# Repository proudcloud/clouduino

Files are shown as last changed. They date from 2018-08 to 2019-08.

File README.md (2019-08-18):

# Clouduino

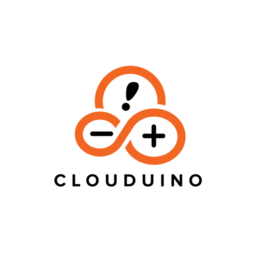
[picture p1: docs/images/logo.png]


Clouduino is a fully open-source, WiFi mesh-enabled embedded development platform.

This project is still in its infancy. At the moment, the circuit design and PCB layout for the initial prototype version is available for building the initial iteration of the board: Clouduino Stratus. We also included sample code to get you started. We will be producing limited quantities of the board soon. In the meantime, let's build our own boards, send us your feed back and help this project grow.

## Specs

- CPU: 160 MHz
- L106 32-bit RISC Tensilica Xtensa Diamond Standard 106Micro
- 3.3V supply power
- Flash Memory: 4MB
- 16 GPIO pins
- 8 analog input channels with 12-bit resolution (programmable as single-ended or pseudo-differential pairs)
- SPI
- I2C support
- 12-bit SAR ADC support
- IEEE 802.11 b/g/n WiFi (w/ WEP, WPA, WPA2)

## Getting Started
Check out our Get Started Guide [here](https://github.com/proudcloud/clouduino/tree/master/getStarted).

## Quickstart Guide

1. Download and install [Arduino IDE](https://www.arduino.cc/en/Main/Software)
2. Follow [this guide](https://github.com/proudcloud/clouduino/tree/master/getStarted) to configure the IDE and upload your first sketch
3. Follow our [examples](https://github.com/proudcloud/clouduino/tree/master/example)

## Build Your Own Board

Schematic diagrams and breadboard prototype can be found in [this folder](https://github.com/proudcloud/clouduino/tree/master/schematics)

### Materials Needed
#### MCU
- 1 x ESP12F

#### Peripherals
- 1 x MCP23S17 GPIO Expander (SOIC)
-  1 x MCP3208 ADC (SOIC)

#### Connectors and Interfacing
- 1 x FT230XS-R USB to Serial (SSOP)
- 1 x USB-B Mini Connector
- 2 x 16-pin Female/Male headers

#### Power
 - 1 x AMS1117 - 3.3 Regulator (SOT-223-3)

#### Others
 - 1 x ECQ10A04-F Dual Schottky Barrier (TO-252)
 - 2 x BC847W (SOT323)
 - 7 x 10K 1% SMD 0603 Resistors
 - 2 x 27 ohm 1% SMD 0603 Resistors
 - 3 x 270 ohm 1% SMD 0603 Resistors
 - 2 x 470 ohm 1% SMD 0603 Resistors
 - 3 x 0.1uF 50V SMD 0603 Capacitor
 - 2 x 10uF 50V SMD 0603 Capacitor
 - 1 x 1uF 50V SMD 0603 Capacitor
 - 2 x 47pF 50V SMD 0603 Capacitor
 - 1 x SMD LED 0603 Green
 - 1 x SMD LED 0603 Yellow
 - 1 x SMD LED 0603 Blue
 - 2 x OMRON BF-3 1000 THT Tact Switch 
 - 1 x Ferrite Bead 600/100mhz SMD 0603

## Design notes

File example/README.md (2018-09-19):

# Uploading Sketches to Clouduino using Arduino IDE #
1. Enter Flash mode by toggling the switch to "Flash mode" for the first 3 seconds of connecting Clouduino to a USB port on your device. This mode allows sketches to be uploaded to your Clouduino. (For testers: Toggle switch for perfboard prototype, OMRON switch for PCB)
2. Check the Port number designated to your Clouduino.
    - For Windows: Find the COM Port number in the Device Manager
    - For MAC: Open terminal and type: "ls /dev/*"
    - For Linux: Open terminal and type: "ls /dev/tty*"
3. Choose Tools Menu -> Board -> "Generic ESP8266 Module" under ESP8266 Modules
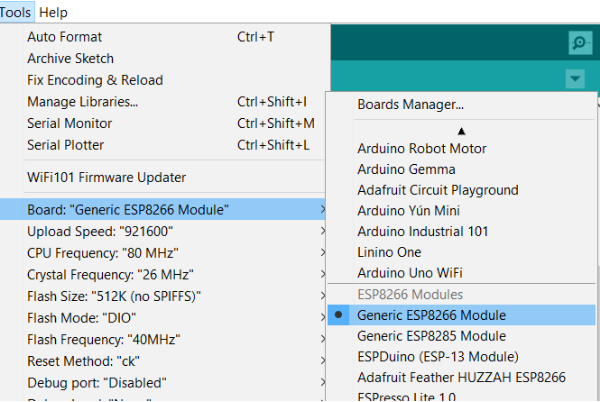
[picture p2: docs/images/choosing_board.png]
choosing_board
    
4. Suggested Tools settings:
    - Flash Mode -> "DIO"
    - Flash Size -> “512K (no SPIFFS)”
    - Debug port -> “Disabled” 
    - Debug Level -> “None”
    - IwIP Variant -> “v2 Lower Memory”
    - Reset Method -> “ck”
    - Crystal Frequency -> “26MHz”
    - Flash Frequency -> “40MHz”
    - CP U Frequency -> “80 MHz”
    - Builtin Led -> “2”
    - Upload Speed -> “921600” (Optional, for fastest upload speed)
    - Erase Flash -> “Only Sketch”

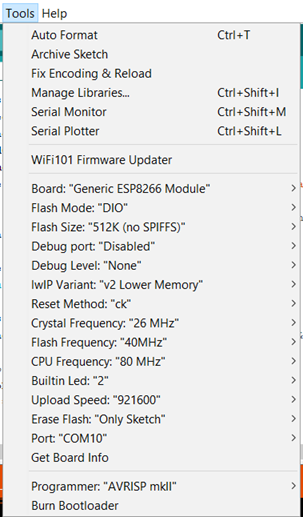
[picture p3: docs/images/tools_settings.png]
tools_settings
    
5. Choose the correct serial port for your board.
    - Choose Tools -> Port -> comX or /dev/tty.usbmodemXXXXX. (where X marks a sequentially or randomly assigned number.
6. Click the Upload icon.

Note: Enter Normal mode by toggling the switch to "Normal mode" then press Reset button.  This is to run your program after flashing a program on your clouduino.

#  Debugging and Troubleshooting #
Failed upload is a common issue with programming ESP8266, (eg: "espcomm_sync failed" error), when encountered please try the following methods:
 - Toggle switch to Flash mode then press reset button.
 - Check if powersupply is sufficient. VCC pin should receive a stable 3.3V. Any lower than 2.9V supplied power causes upload to fail nor would the Clouduino function properly even on normal mode.
 - Use a very short USB cable as much as possible. Very long cables to tend fail UART communication due to delay induced by excess cable length.

Double-check your code:
 - Make sure to include SPI.h for anything involving GPIO or ADC pin applications to enable slave select on ESP.
 - Don't forget to include MCP23S17.h if utilizing GPIO pins, and MCP3208.h for analog reading and conversion using analog pins.

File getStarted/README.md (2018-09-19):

# Getting Started with Clouduino Stratus #
This document explains how to connect your Clouduino board to the computer and upload your first sketch. 

- Clone or download the Clouduino Github repository 
- Use your Clouduino Stratus on the Arduino Desktop IDE
- Install the board drivers and other library dependencies
- Open your first sketch
- Select the board type and port
- Upload the program
- Sample Projects and Tutorials

## Clone or download the Clouduino Github repository ##
To get started, you must first clone or download then unzip the [Clouduino repository](https://github.com/proudcloud/clouduino).
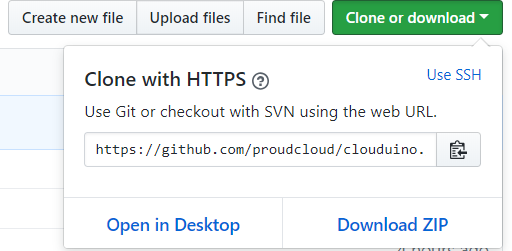
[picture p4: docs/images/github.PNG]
clouduino_repo
    

## Use your Clouduino Stratus on the Arduino Desktop IDE ##
If you want to program your Clouduino Stratus then you will need to install the [Arduino Desktop IDE](https://www.arduino.cc/en/Main/Software). To connect the Clouduino Stratus to your computer, you’ll need a Mini-B USB cable. This also provides power to the board. 

## Install the board drivers and other library dependencies ##

Let's start with installing the ESP8266 board driver with boards manager in Arduino IDE. 

1. Start Arduino. Click on File menu then select Preferences.
2. Enter `http://arduino.esp8266.com/stable/package_esp8266com_index.json` into Additional Board Manager URLs field. You can add multiple URLs, separating them with commas. 
    
3. Open Boards Manager from Tools > Board menu and install the latest stable esp8266 platform 
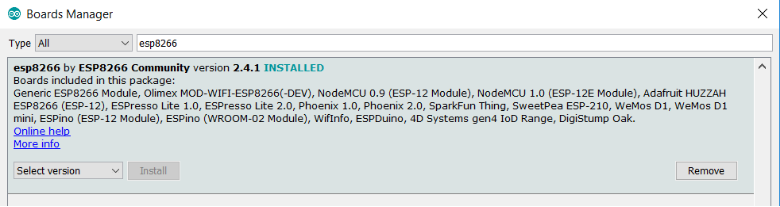
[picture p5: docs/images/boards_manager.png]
boards_manager
    
4. Go to Tools again >  Board > Select Generic ESP8266 Module.
    choosing_board
    - ESP8266 Arduino core documentation [link](https://arduino-esp8266.readthedocs.io/en/2.4.2/).
    - ESP8266 Arduino core github [link](https://github.com/esp8266/Arduino)
 
There are two essential libraries you must install for Clouduino: [MCP23S17](https://github.com/n0mjs710/MCP23S17) for controlling GPIO pins and [MCP3208](https://github.com/labfruits/mcp3208) for controlling ADC pins. 
You have to import these libraries to Arduino IDE by simple following the steps below:

1. First download these libraries as ZIP file. No need to unzip, leave it as it is.
    - [MCP23S17](https://github.com/n0mjs710/MCP23S17)  - GPIO Expander
    - [MCP3208](https://github.com/labfruits/mcp3208)   - ADC Expander
2. In the Arduino IDE, navigate to Sketch menu > Include Library > Add .ZIP Library > Select Add .ZIP Library > Find and open MCP3208-master ZIP file.
3. Repeat step 2 for MCP23S17-master ZIP file.
   
Note that you only have to install the ESP8266 board driver and the two essential libraries once. Do, however, check for library updates often at the library manager!

## Open your first sketch ##
You are now ready to try out your first sketch in Arduino IDE.
 1.  Open File menu > Go to Clouduino folder directory > example folder > Blink folder > Open Blink.ino
 2.  Under example/Blink folder, you will see a breadboard and schematic for Blink, showing a circuit with Clouduino connected to an LED - Assemble the circuit.

Blink LED circuit - Breadboard:
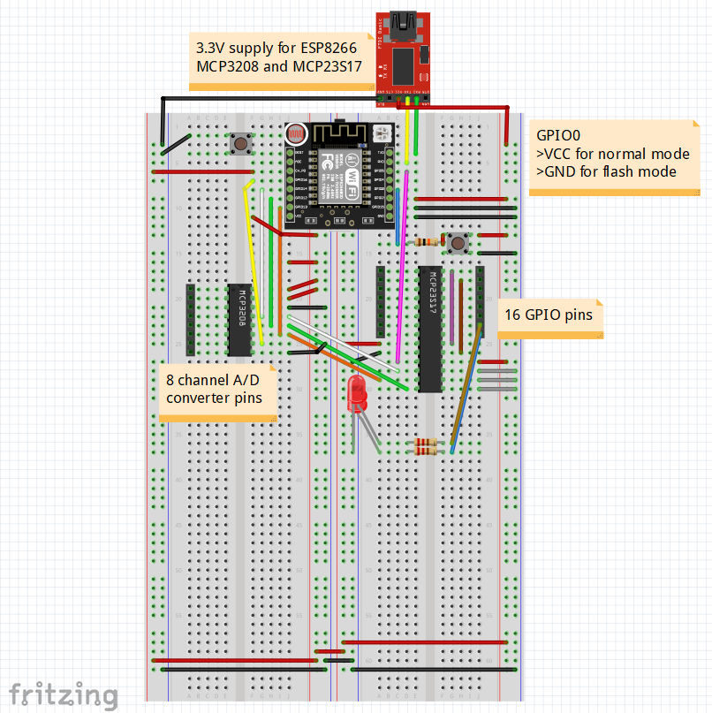
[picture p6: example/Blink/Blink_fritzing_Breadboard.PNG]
Blink_Breadboard
    
Blink LED circuit - Schematics:
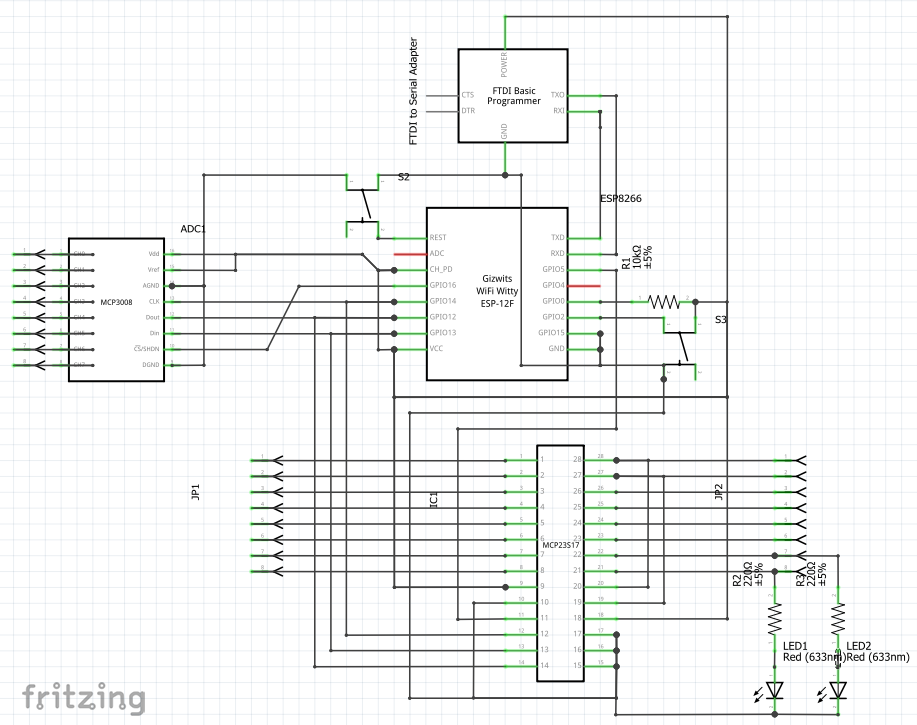
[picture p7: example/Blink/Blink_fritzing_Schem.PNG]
Blink_Schematics
    

## Upload your first sketch 

1. Enter Flash mode by toggling the switch to "Flash mode" for the first 3 seconds of connecting Clouduino to a USB port on your device. This mode allows sketches to be uploaded to your Clouduino. (For testers: Toggle switch for perfboard prototype, OMRON switch for PCB)
2. Check the Port number designated to your Clouduino.
    - For Windows: Find the COM Port number in the Device Manager
    - For MAC: Open terminal and type: "ls /dev/*"
    - For Linux: Open terminal and type: "ls /dev/tty*"
3. Choose Tools Menu -> Board -> "Generic ESP8266 Module" under ESP8266 Modules
    choosing_board
4. Suggested Tools settings:
    - Flash Mode -> "DIO"
    - Flash Size -> “512K (no SPIFFS)”
    - Debug port -> “Disabled” 
    - Debug Level -> “None”
    - IwIP Variant -> “v2 Lower Memory”
    - Reset Method -> “ck”
    - Crystal Frequency -> “26MHz”
    - Flash Frequency -> “40MHz”
    - CP U Frequency -> “80 MHz”
    - Builtin Led -> “2”
    - Upload Speed -> “921600” (Optional, for fastest upload speed)
    - Erase Flash -> “Only Sketch”

    tools_settings
5. Choose the correct serial port for your board.
    - Choose Tools -> Port -> comX or /dev/tty.usbmodemXXXXX. (where X marks a sequentially or randomly assigned number.
6. Click the Upload icon.

Note: Enter Normal mode by toggling the switch to "Normal mode" then press Reset button.  This is to run your program after flashing a program on your clouduino.

##  Debugging and Troubleshooting ##
Failed upload is a common issue with programming ESP8266, (eg: "espcomm_sync failed" error), when encountered please try the following methods:
 - Toggle switch to Flash mode then press reset button.
 - Check if powersupply is sufficient. VCC pin should receive a stable 3.3V. Any lower than 2.9V supplied power causes upload to fail nor would the Clouduino function properly even on normal mode.
 - Use a very short USB cable as much as possible. Very long cables to tend fail UART communication due to delay induced by excess cable length.
  
 Double-check your code:
 - Make sure to always include SPI.h for anything involving GPIO or ADC pin applications to enable slave select on ESP.
 - Don't forget to include MCP23S17.h if utilizing GPIO pins, and MCP3208.h for analog reading and conversion using analog pins.

## Sample Projects and Tutorials ##
Now that you have set up and programmed your Clouduino Stratus, you may learn more ideas on how to control your Stratus by trying other sample sketches at [example](https://github.com/proudcloud/clouduino/tree/master/example) folder such as controlling GPIO pins and doing analog reading using ADC pins. Hopefully these would give you insights and inspiration while exploring possibilities with Stratus.
 - Blinky - A sketch that uses all 16 available GPIO pins of Clouduino Stratus to blink LEDs.
 - ADC test LDR - A sketch that demonstrates Analog reading and analog to digital conversion using LDR (Light Dependent Resistor). 
- Clouduino Webserver LEDs - A sketch for creating a webserver on Clouduino to control two LEDs remotely.
- Painless Mesh - A sketch that demonstrates pseudo-mesh networking with Clouduino. (Requires two or more ESP’s or Clouduino boards)

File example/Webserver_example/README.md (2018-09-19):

# Webserver with Clouduino Stratus ##

In this project you’ll create a standalone web server with Clouduino Stratus that can toggle two LEDs using Arduino IDE. This Web server is mobile responsive and it can be accessed with any device that as a browser in your local network. This tutorial is derived from [ESP822 Webserver with Arduino IDE](https://randomnerdtutorials.com/esp8266-web-server-with-arduino-ide/).

### Follow these steps:

-  Assemble the circuit based from the Fritzing schematic or breadboard.
-  Upload the Clouduino_Webserver_LEDs sketch to Clouduino. 
-  Open the Arduino serial monitor at a baud rate of 115200.
-  Press Reset button. After a few seconds your IP address should appear.
-  
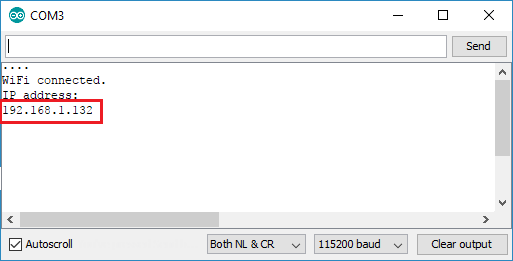
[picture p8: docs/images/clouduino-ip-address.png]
ip-address


### Demonstration
For the final demonstration open any browser from a device that is connected to the same router that your ESP is. Then type the IP address and click Enter!

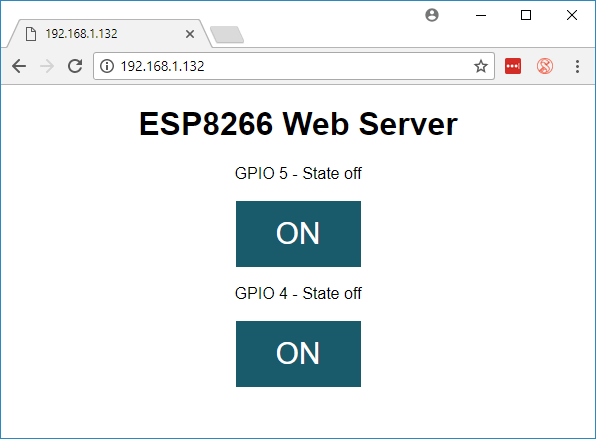
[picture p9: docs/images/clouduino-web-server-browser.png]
webserver_pc


From your smartphone browser:

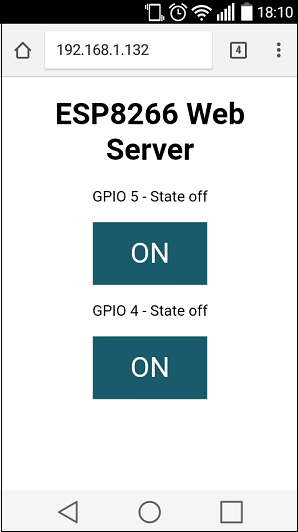
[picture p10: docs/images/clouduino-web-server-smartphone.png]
webserver_cp


Now when you press the buttons in your web server you can control both LEDs remotely.

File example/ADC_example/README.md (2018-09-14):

#		USING THE ADC PINS

Clouduino uses the [Microchip 2.7V 8-Channel 12-Bit A/D Converters with SPI Serial Interface Class](https://github.com/labfruits/mcp3208).

  * 12-bit resolution
  * 8 input channels
  * Analog inputs programmable as single-ended or pseudo-differential pairs
  * Fixed 3.3V Single supply operation
  * Fixed 3.3V Reference voltage

Here are commonly used methods in controlling the ADC pins for Clouduino. 

   * Channel
   * MCP3208()
   * pinMode()
   * digitalWrite()
   * digitalRead()
   * read()
   * testSplSpeed()
   * toAnalog()
   * toDigital()
   * getVref()
   * getAnalogRes()

##            Methods and Functions

### Channel ch      

    SINGLE_0 = 0b1000,      // single channel 0 
    SINGLE_1 = 0b1001,      // single channel 1 
    SINGLE_2 = 0b1010,      // single channel 2 
    SINGLE_3 = 0b1011,      // single channel 3 
    SINGLE_4 = 0b1100,      // single channel 4 
    SINGLE_5 = 0b1101,      // single channel 5 
    SINGLE_6 = 0b1110,      // single channel 6 
    SINGLE_7 = 0b1111,      // single channel 7 

    DIFF_0PN = 0b0000,      // differential channel 0 (input 0+,1-) 
    DIFF_0NP = 0b0001,      // differential channel 0 (input 0-,1+)
    DIFF_1PN = 0b0010,      // differential channel 1 (input 2+,3-) 
    DIFF_1NP = 0b0011,      // differential channel 1 (input 2-,3+) 
    DIFF_2PN = 0b0100,      // differential channel 2 (input 4+,5-) 
    DIFF_2NP = 0b0101,      // differential channel 2 (input 5-,5+) 
    DIFF_3PN = 0b0110,      // differential channel 3 (input 6+,7-) 
    DIFF_3NP = 0b0111       // differential channel 3 (input 6-,7+) 

### MCP3208() ###

Description

Initiates a MCP3208 object. The chip select pin must be already configured as output. The default SPI interface will be used for communication.

Syntax

    MCP3208(uint16_t vref, uint8_t csPin);

Parameters

    vref:   ADC reference voltage in mV. Fixed at 3.3V for Clouduino.
    csPin:  pin number to use for chip select. Fixed at GPIO pin 16 for Clouduino.

Returns    

    none

Example

    MCP3208 adc(3300, 16);    //3.3V Vref with SPI slave select at pin 16 

### read() ###

Description    

Reads the supplied channel. The SPI interface must be initialized and put in a usable state before calling this function.

Syntax

    read(Channel ch);

Parameter    

    ch: defines the channel to read from.

Returns

    The converted raw value.

Example 1

    sensor1_val = adc.read(MCP3208::SINGLE_0); //Read Single channel 0 of MCP3208

Example 2

    sensor2_val = adc.read(MCP3208::DIFF_0NP); //Read differential channel 0 (input 0+,1-)

Example 3

    sensor3_val = adc.read(MCP3208::0b0001);  // differential channel 0 (input 0-,1+))

### testSplSpeed() ###

Description

Performs a sampling speed test. The SPI interface must be initialized and put in a usable state before calling this function.

Syntax

    testSplSpeed(Channel ch, uint16_t num);

Parameters

    ch:     the channel to use for the speed test.
    num:    the number of reads to perform.

Returns

    The average sampling time needed for one read in us.

Example

    uint16_t speed = testSplSpeed(SINGLE_0, 3);

### toAnalog() ###

Description

Converts the supplied raw value to an analog value in mV based on the defined reference voltage.

Syntax

    toAnalog(uint16_t raw);

Parameter

    raw: the sampled ADC value.

Returns

    The converted analog value in mV.

Example

    uint16_t raw = adc.read(MCP3208::SINGLE_0);
    uint16_t val = toAnalog(raw);

### toDigital() ###

Description

Converts the supplied analog value to the digital representation based on the defined reference voltage.

Syntax

    toDigital(uint16_t val);

Parameter

    val: the analog value in mV.

Returns

    The digital representation off the supplied analog value.

Example

    uint16_t raw = adc.read(MCP3208::SINGLE_0);
    uint16_t val = toAnalog(raw);
    uint16_t lvl = toDigital(val);

### getVref() ###

Description

Returns the reference voltage.

Syntax

    getVref();

Parameters

    none

Returns 

    The configured reference voltage in mV.

Example

    ref = getVref();

### getAnalogRes() ###

Description

    Returns the analog resolution in µV based on the defined reference voltage.

Syntax

    getAnalogRes();

Parameters

    none

Returns    

    The analog resolution in µV.

Example

    uint16_t res = getAnalogRes();

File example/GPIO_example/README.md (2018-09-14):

#		USING THE GPIO PINS

Clouduino uses the [Microchip MCP23S17 SPI I/O Expander Class created by Cort Buffington & Keith Neufeld](https://github.com/n0mjs710/MCP23S17).

The goal of their implementation is to provide a software interface that mimics the existing Arduino I/O functions such as:

  * pinMode(pin, mode)
  * digitalWrite(pin, value)
  * digitalRead(pin)

Here are commonly used methods and functions for controlling the GPIO pins of Clouduino. 

   * MCP()
   * begin()
   * pinMode()
   * pullupMode()
   * inputInvert()
   * digitalWrite()
   * digitalRead()
   * wordWrite()
   * byteWrite()
   * byteRead()

##			METHODS AND FUNCTIONS

### MCP() ###

Description

Instantiates the GPIO expander chip as an object.

Syntax

    MCP object_name(address, slave-select)

Parameters

    object_name: any arbitrary name given to create the object
    address: address (0-7) of the device configured with address (pins A0, A1, A2)
    slave-select: No range checking! Make sure you use one that makes sense.

Returns

    none

Example

    MCP IOchip(0,5);    // create an object at address 0 called "Iochip" with SlaveSelect at GPIO pin 5 of ESP 
				        // By default Clouduino's GPIO chip is addressed to 0.

### begin() ###

Description

Enable the SPI bus and configure the slave select pin for this object. You must call this in the Arduino void setup()function.

Syntax

    object.name.begin();

Parameters

    None

Example

    void setup() {
        IOChip.begin();
    }

### pinMode() ###

Description

Configure pin(s) as either input or output on the selected object (device specified by an address)
        
Syntax

    object.name.pinMode(pin, mode);
    or
    object.name.pinMode(mode);

Parameters

    object_name: the name given when this object was created
    pin: the pin number (1-16) on which to set as input or output
    mode: To specify whether the pin is either a "HIGH" (1) for input (default) or a "LOW" (0) for output. If a pin is not specified, mode should be a word indicating the mode of each of the 16 I/O pins on the chip. Or simply indicate - OUTPUT or INPUT.

Returns

    none

Example 1

    void setup() {
        IOChip.pinMode(1, INPUT); // sets pin 1 as input
        IOchip.pinMode(2, OUTPUT); // sets pin 2 as an output
        IOchip.pinMode(15, HIGH); // sets pin 15 as an input
        IOchip.pinMode(16, LOW); // sets pin 16 as an output
    }

Example 2

    void setup() {
        IOchip.pinMode(0B0000111100001111); // sets pins 1-4 and 9-12 as input, 5-8 and 13-16 as output
    }

### pullupMode() ###

Description

Configure the weak pull-up resistors on pins defined as inputs
This has no effect on pins that are configured as outputs.

Syntax

    object_name.pullupMode(pin, mode);
    or
    object_name.pullupMode(mode);

Parameters

    object_name: the name given when this object was created
    pin: the pin number (1-16) on which to enable or disable the internal weak pull-up resistor
    mode: if a pin is specified, either "HIGH" (1) to enable or "LOW" (0) to disable (default) the weak pull-up resistor on the specified pin. If a pin is not specified, mode should be a word indicating the pull-up mode of each of the 16 pins on the chip. Configuring pull-up has no effect on pins while they are configured as output.

Returns

    none

Example 1

    void setup() {
        IOchip.pullupMode(4, HIGH); // enable the pull-up on pin 4
    }

Example 2

    void setup() {
        IOchip.pullupMode(0B0000111100000000); // enable the pull-ups on pins 9-12
    }

### inputInvert() ###

Description

Configure inversion on pins configured as inputs.
This will cause an inverted input pin to read as "LOW" (0) when it is actually in a high state, or as "HIGH" (1) when it is actually in a low state. This has no effect on pins that are configured as outputs.

Syntax

    object_name.inputInvert(pin, inversion);
    or
    object_name.inputInvert(inversion);

Parameters

    object_name: the name given when this object was created
    pin: the pin number (1-16) on which to set or clear inversion
    inversion: if a pin is specified, either "HIGH" (1) is specified to enable, or "LOW" (0) to disable (default) inversion on the specified pin. If a pin is not specified, mode should be a word indicating the inversion state of each of the 16 pins on the chip. Configuring inversion has no effect on pins while they are configured as output.

Returns

    none

Example 1

    void setup() {
        IOchip.inputInvert(4, LOW); // disable inversion on pin 4
    }

Example 2

    void setup() {
        IOchip.inputInvert(0B0000000000001111); // enable inversion on pins 1-4
    }

### digitalWrite() ###

Description

Write a "HIGH" or "LOW" value to a digital I/O pin(s)

Syntax

    object_name.digitalWrite(pin, value);
    or
    object_name.digitalWrite(value);

Parameters

    object_name: the name given when this object was created
    pin: the pin number (1-16) who's value will be set
    value: if a pin is specified, either a "HIGH" (1) or a "LOW" (0) value may be set on the specified pin. If a pin is not specified, value should be a word indicating the output state of all 16 pins on the device. Writing pins configured as inputs has no effect.

Returns

    none

Example 1

    void loop() {
        IOchip.digitalWrite(16, HIGH); // set pin 16 to "HIGH"
    }

Example 2

    void loop() {
        IOchip.digitalWrite(0B1100000000110000); // Set 5, 6, 15 & 16 to high, 7,8, 13 & 14 to low - inputs ignored
    }

### digitalRead() ###

Description

Reads the value of input pin(s), either "HIGH" ("1") or "LOW" ("0)

Syntax

    object_name.digitalRead(pin);
    or
    object_name.digitalRead();

Parameters

    object_name: the name given when this object was created
    pin: the pin number (1-16) who's value will be read. If no pin number is supplied, a word will be read containing the input state of all pins. The values for pins configured as output should be disregarded if the "word-mode" version is used.

Returns

    "HIGH" (1) or "LOW" (0) if a pin is supplied. a word (16 bits) is returned if no pin argument is given.

Example 1

    void loop() {
        int val;
        val = IOchip.digitalRead(4); // assigns the value of pin4 to onevalue
    }

Example 2

    void loop() {
        int val;
        val = IOchip.digitalRead(); // assigns the value of all 16 I/O pins to twovalue
    }

### wordWrite() ###

Description

This is an advanced method to write a register pair in the MCP23S17. This class operates the MCP23S17 in "BANK=0" mode. The intention is that a registers for both ports may be written by supplying a single word as an argument. The low byte is written to the register address supplied, and the high byte to the next higher register address.

Syntax

    object_name.wordWrite(base register, value);

Parameters

    object_name: the name given when this object was created
    base register: the beginning register address to write, for example, if 0x02 is given, the low byte of "value" will be written to 0x02 and the high byte of "value" to the register at 0x03
    value: a word (unsigned int) that will be broken into two bytes and written to two consecutive registers, starting with the "base register" address

Returns

    none

Example

    void loop() {
        IOchip.wordWrite(0x12, 0xFF00); // Set GPIOA to 0x00 and GPIOB to OxFF
    }

### byteWrite() ###

Description

This is an advanced method to write any single register in the MCP23S17.

Syntax

    object_name.byteWrite(register, value);

Parameters

    object_name: the name given when this object was created
    register: the register address to write
    value: a byte (unsigned char) that will be written to the specified registers

Returns

    none

Example

    void loop() {
        IOchip.byteWrite(0x13, 0xF0); // Set GPIOB (portB) to 0xF0 (0B11110000) 
    }

### byteRead() ###

Description

This is an advanced method to read any single register in the MCP23S17.

Syntax

    object_name.byteRead(register);

Parameters

    object_name: the name given when this object was created
    register: the register address to be read

Returns

    unsigned char (uint8_t)

Example

    void loop() {
        int val;
        val = IOchip.byteRead(0x12); // Read GPIOA (portA)
    }

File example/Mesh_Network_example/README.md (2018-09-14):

## Disclaimer ##

The mesh library of ESP8266 Core for Arduino (v2.4.0) is under very active development at the moment. As of September 2018, the mesh library still can't mesh properly. That is - although messages can directly be exchanged with immediate nodes, messages cannot multihop to other nodes. Hence for now, Painless mesh library will be used just as a placeholder sample sketch for demonstrating a pseudo-mesh networking with Clouduino.

A working Mesh library is underway.

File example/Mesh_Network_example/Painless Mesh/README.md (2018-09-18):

# Library Dependencies of PainlessMesh #
painlessMesh makes use of the following libraries, which can be installed through the Arduino Library Manager:
+ [ArduinoJson](https://github.com/bblanchon/ArduinoJson)
+ [TaskScheduler](https://github.com/arkhipenko/TaskScheduler)
+ [ESPAsyncTCP (ESP8266)](https://github.com/me-no-dev/ESPAsyncTCP) 

For information on installing libraries, see: http://www.arduino.cc/en/Guide/Libraries

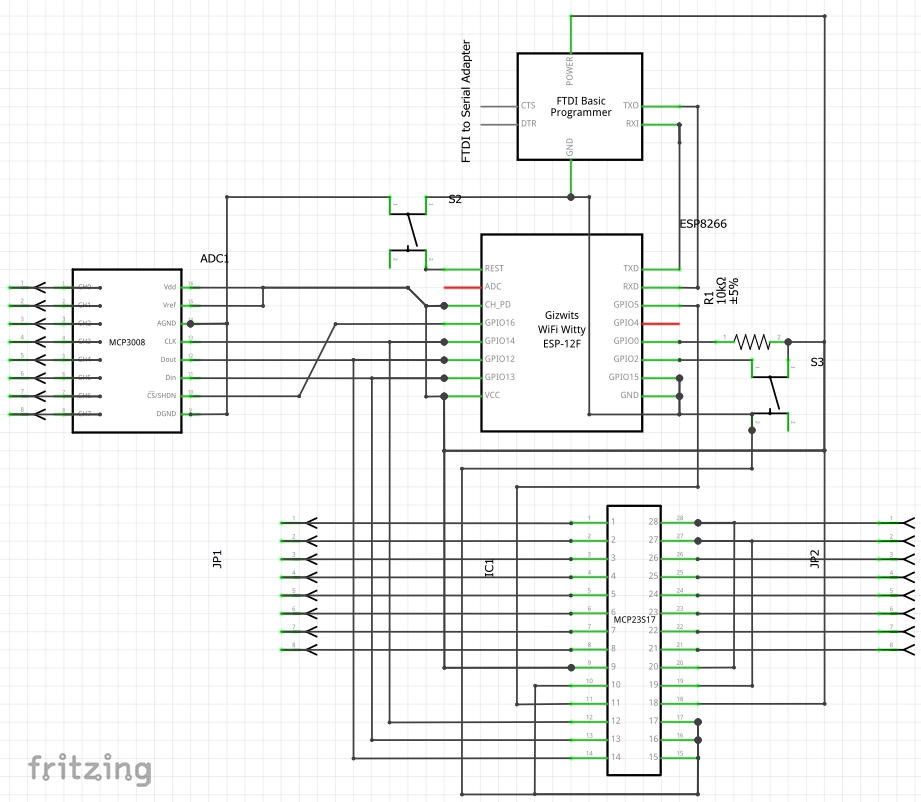
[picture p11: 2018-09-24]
schematics/Clouduino_Fritzing_Schem.PNG

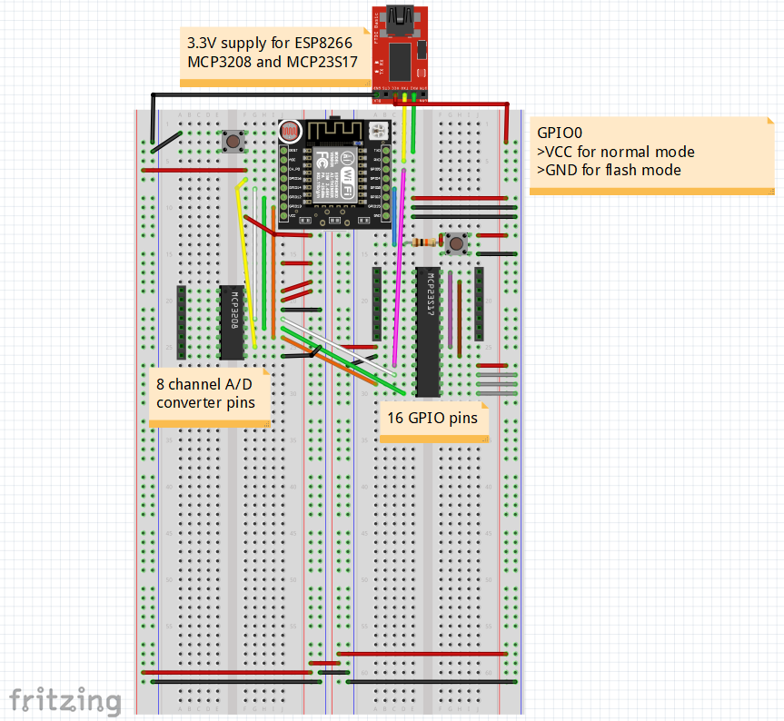
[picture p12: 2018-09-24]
schematics/Clouduino_Fritzing_Breadboard.PNG

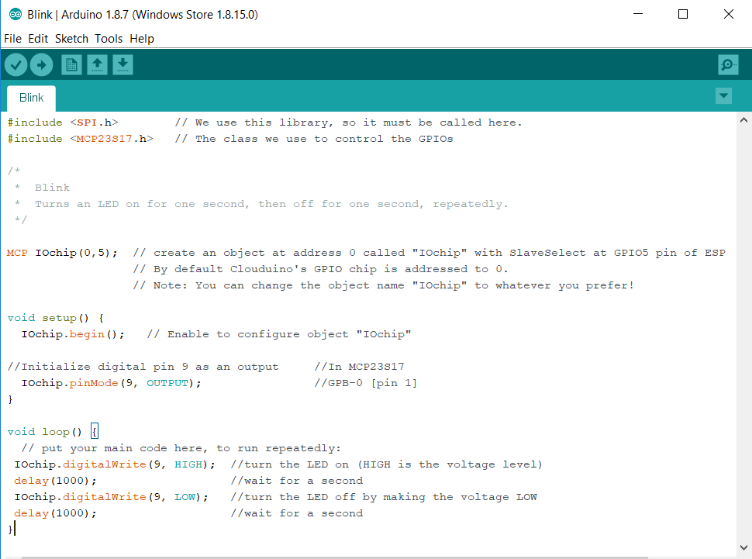
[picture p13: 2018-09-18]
docs/images/blink_sketch.png

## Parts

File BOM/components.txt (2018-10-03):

[MCU]
1 x ESP12F
----------------------------------------------------------------
[Peripherals]
1 x MCP23S17 GPIO Expander (SOIC)
1 x MCP3208 ADC (SOIC)
----------------------------------------------------------------
[Connectors and Interfacing]
1 x FT230XS-R USB to Serial (SSOP)
1 x USB-B Mini Connector
2 x 16-pin Female/Male headers
----------------------------------------------------------------
[Power]
1 x AMS1117 - 3.3 Regulator
----------------------------------------------------------------
[Others]
2 x B250-13-F 50V 2A Schottky Diodes 
4 x 10K 1% SMD 1206 Resistors
2 x 27 ohm 1% SMD 1206 Resistors
1 x 270 ohm 1% SMD 1206 Resistors
1 x 470 ohm 1% SMD 1206 Resistors
4 x 0.1uF 50V SMD 1206 Capacitor
2 x 10uF 50V SMD 1206 Capacitor
2 x 47pF 50V SMD 1206 Capacitor
1 x SMD LED 1206 Green
2 x OMRON BF-3 1000 THT Tact Switch 
1 x Ferrite Bead 600/100mhz SMD 0805

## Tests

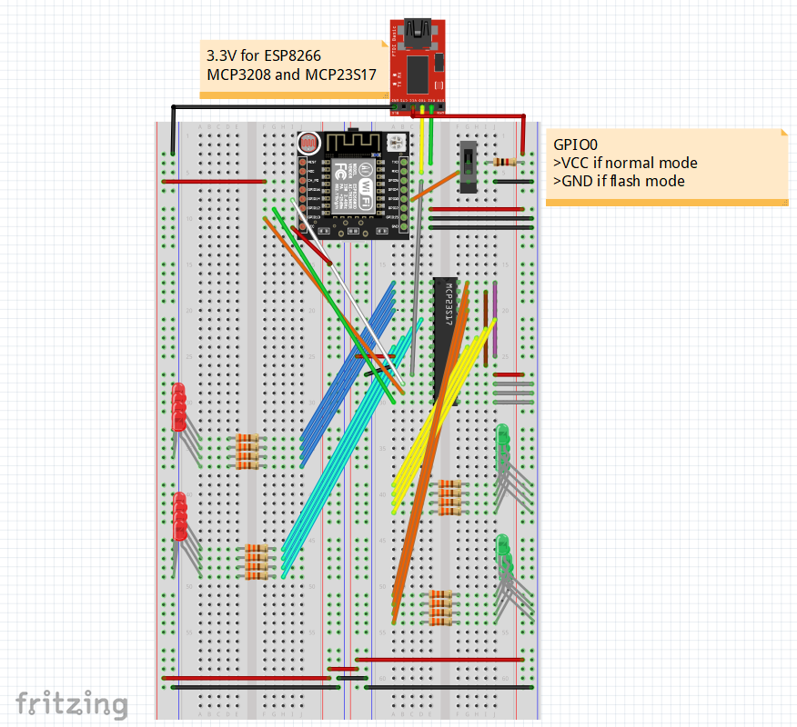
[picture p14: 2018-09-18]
example/GPIO_example/GPIO_test_Blinky_fritzing_Breadboard.PNG

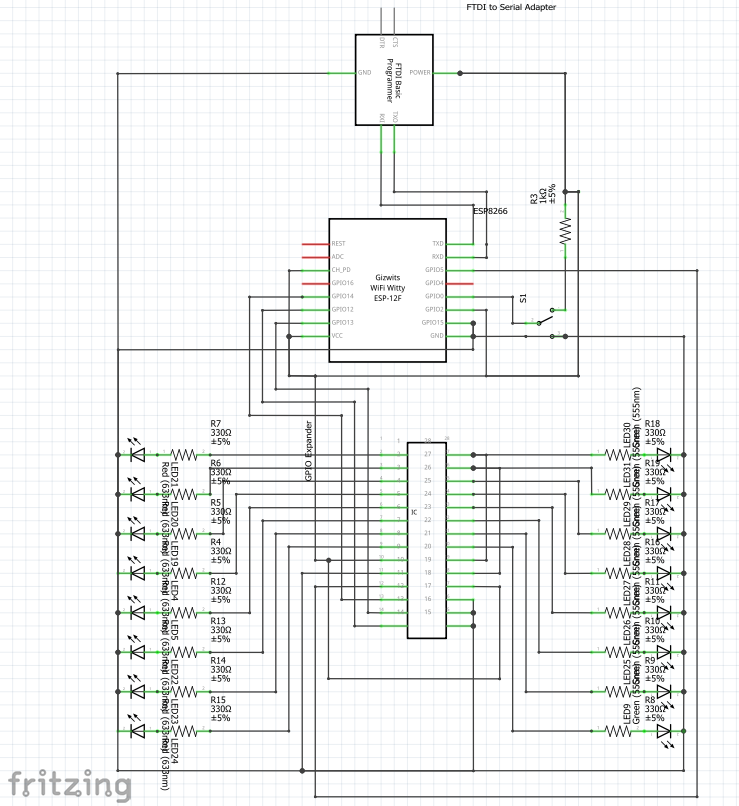
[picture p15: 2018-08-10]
example/GPIO_example/GPIO_test_Blinky fritzing_Schem.PNG

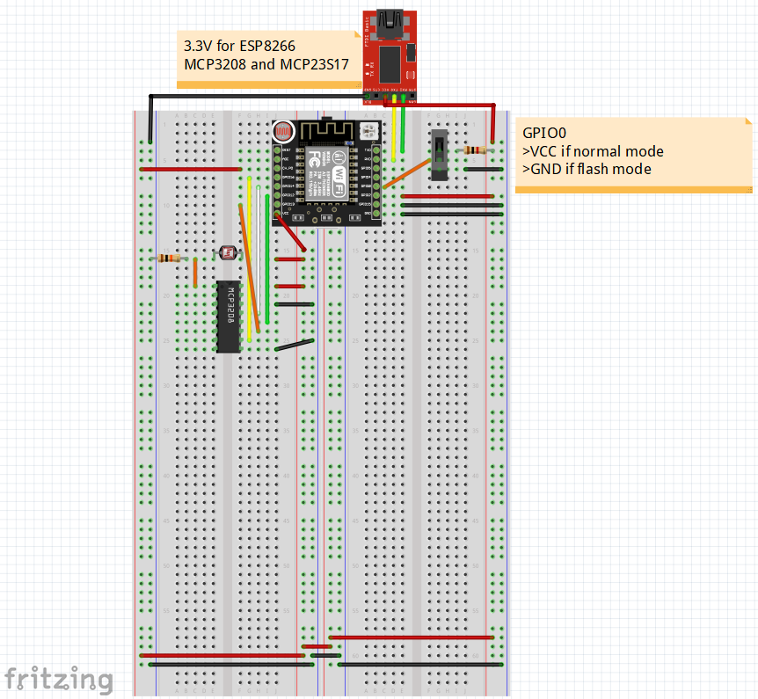
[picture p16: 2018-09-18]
example/ADC_example/ADC_test_LDR_fritzing_Breadboard.PNG

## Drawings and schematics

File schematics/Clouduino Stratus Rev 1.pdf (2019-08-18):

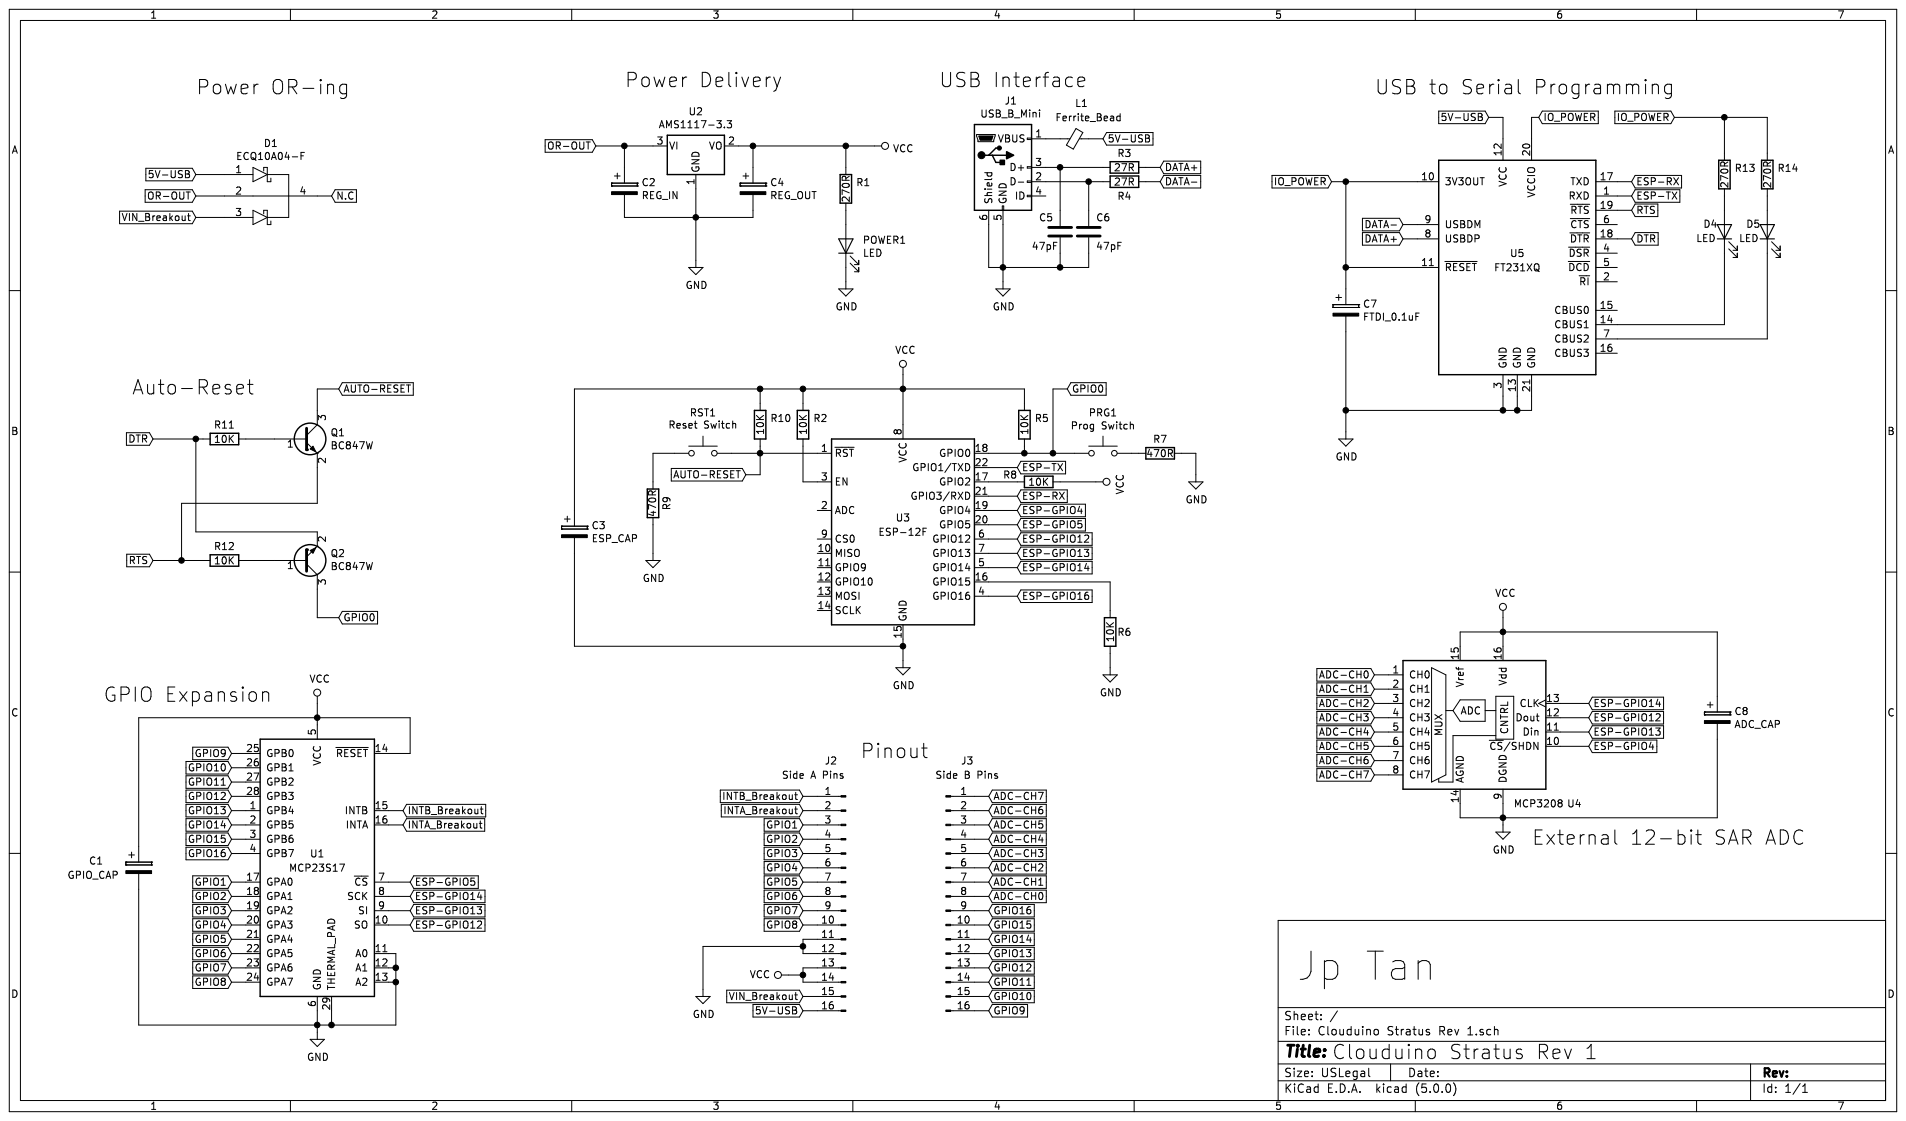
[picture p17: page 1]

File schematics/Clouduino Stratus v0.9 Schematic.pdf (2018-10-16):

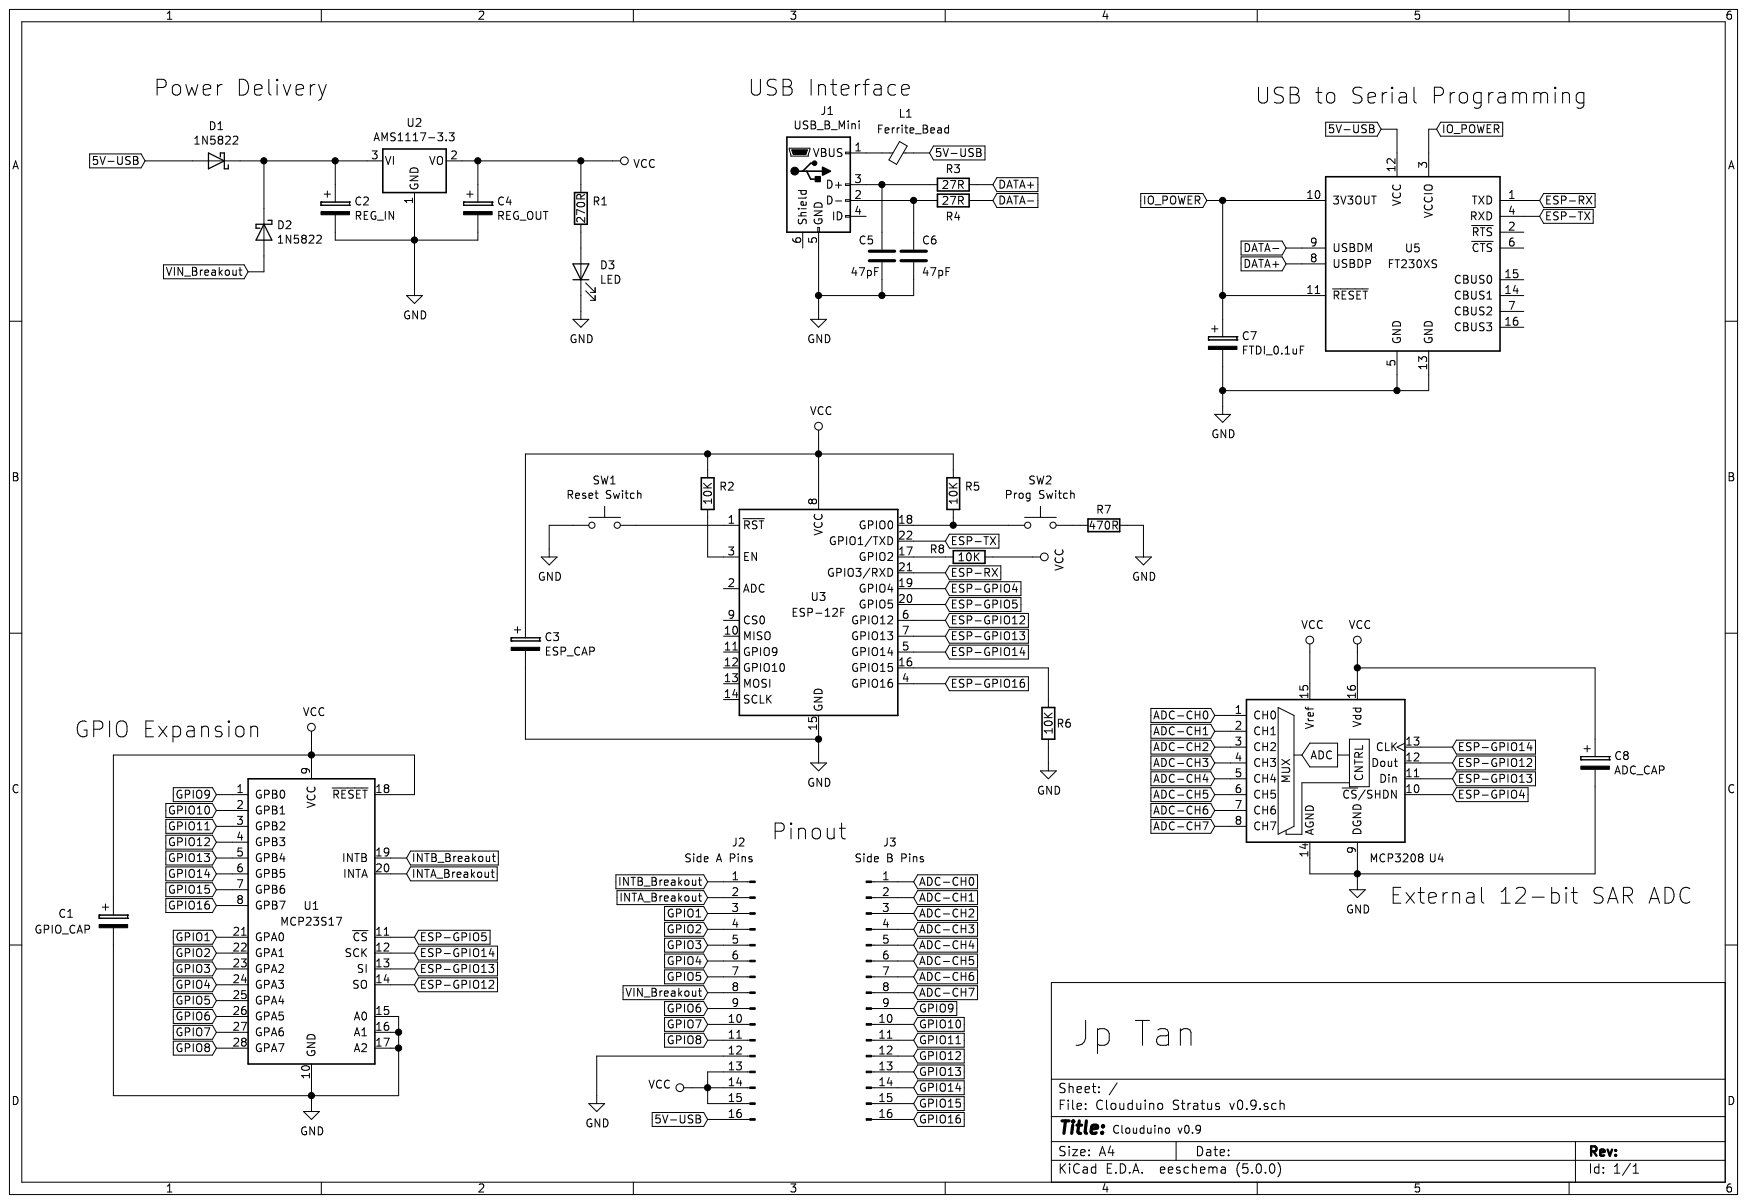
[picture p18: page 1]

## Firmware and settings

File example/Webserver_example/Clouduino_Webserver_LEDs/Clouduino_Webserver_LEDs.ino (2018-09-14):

/*********
  Rui Santos
  Complete project details at http://randomnerdtutorials.com  
*********/

// Load Wi-Fi library
#include <ESP8266WiFi.h>
#include <MCP23S17.h>
MCP IOchip(0,5);

// Replace with your network credentials
const char* ssid     = "REPLACE_WITH_YOUR_SSID";
const char* password = "REPLACE_WITH_YOUR_PASSWORD";

// Set web server port number to 80
WiFiServer server(80);

// Variable to store the HTTP request
String header;

// Auxiliar variables to store the current output state
String output5State = "off";
String output4State = "off";

// Assign output variables to GPIO pins
const int output5 = 1;
const int output4 = 2;

void setup() {
  Serial.begin(115200);
  IOchip.begin();
  
//Initialize GPIO A             //In MCP23S17
  IOchip.pinMode(output5, OUTPUT);    //GPA-0 [pin 21]
  IOchip.pinMode(output4, OUTPUT);    //GPA-1 [pin 22]
  // Set outputs to LOW
  IOchip.digitalWrite(output5, LOW);
  IOchip.digitalWrite(output4, LOW);

  // Connect to Wi-Fi network with SSID and password
  Serial.print("Connecting to ");
  Serial.println(ssid);
  WiFi.begin(ssid, password);
  while (WiFi.status() != WL_CONNECTED) {
    delay(500);
    Serial.print(".");
  }
  // Print local IP address and start web server
  Serial.println("");
  Serial.println("WiFi connected.");
  Serial.println("IP address: ");
  Serial.println(WiFi.localIP());
  server.begin();
}

void loop(){
  WiFiClient client = server.available();   // Listen for incoming clients

  if (client) {                             // If a new client connects,
    Serial.println("New Client.");          // print a message out in the serial port
    String currentLine = "";                // make a String to hold incoming data from the client
    while (client.connected()) {            // loop while the client's connected
      if (client.available()) {             // if there's bytes to read from the client,
        char c = client.read();             // read a byte, then
        Serial.write(c);                    // print it out the serial monitor
        header += c;
        if (c == '\n') {                    // if the byte is a newline character
          // if the current line is blank, you got two newline characters in a row.
          // that's the end of the client HTTP request, so send a response:
          if (currentLine.length() == 0) {
            // HTTP headers always start with a response code (e.g. HTTP/1.1 200 OK)
            // and a content-type so the client knows what's coming, then a blank line:
            client.println("HTTP/1.1 200 OK");
            client.println("Content-type:text/html");
            client.println("Connection: close");
            client.println();
            
            // turns the GPIOs on and off
            if (header.indexOf("GET /5/on") >= 0) {
              Serial.println("GPIO 5 on");
              output5State = "on";
              IOchip.digitalWrite(output5, HIGH);
            } else if (header.indexOf("GET /5/off") >= 0) {
              Serial.println("GPIO 5 off");
              output5State = "off";
              IOchip.digitalWrite(output5, LOW);
            } else if (header.indexOf("GET /4/on") >= 0) {
              Serial.println("GPIO 4 on");
              output4State = "on";
              IOchip.digitalWrite(output4, HIGH);
            } else if (header.indexOf("GET /4/off") >= 0) {
              Serial.println("GPIO 4 off");
              output4State = "off";
              IOchip.digitalWrite(output4, LOW);
            }
            
            // Display the HTML web page
            client.println("<!DOCTYPE html><html>");
            client.println("<head><meta name=\"viewport\" content=\"width=device-width, initial-scale=1\">");
            client.println("<link rel=\"icon\" href=\"data:,\">");
            // CSS to style the on/off buttons 
            // Feel free to change the background-color and font-size attributes to fit your preferences
            client.println("<style>html { font-family: Helvetica; display: inline-block; margin: 0px auto; text-align: center;}");
            client.println(".button { background-color: #195B6A; border: none; color: white; padding: 16px 40px;");
            client.println("text-decoration: none; font-size: 30px; margin: 2px; cursor: pointer;}");
            client.println(".button2 {background-color: #77878A;}</style></head>");
            
            // Web Page Heading
            client.println("<body><h1>ESP8266 Web Server</h1>");
            
            // Display current state, and ON/OFF buttons for GPIO 5  
            client.println("<p>GPIO 5 - State " + output5State + "</p>");
            // If the output5State is off, it displays the ON button       
            if (output5State=="off") {
              client.println("<p><a href=\"/5/on\"><button class=\"button\">ON</button></a></p>");
            } else {
              client.println("<p><a href=\"/5/off\"><button class=\"button button2\">OFF</button></a></p>");
            } 
               
            // Display current state, and ON/OFF buttons for GPIO 4  
            client.println("<p>GPIO 4 - State " + output4State + "</p>");
            // If the output4State is off, it displays the ON button       
            if (output4State=="off") {
              client.println("<p><a href=\"/4/on\"><button class=\"button\">ON</button></a></p>");
            } else {
              client.println("<p><a href=\"/4/off\"><button class=\"button button2\">OFF</button></a></p>");
            }
            client.println("</body></html>");
            
            // The HTTP response ends with another blank line
            client.println();
            // Break out of the while loop
            break;
          } else { // if you got a newline, then clear currentLine
            currentLine = "";
          }
        } else if (c != '\r') {  // if you got anything else but a carriage return character,
          currentLine += c;      // add it to the end of the currentLine
        }
      }
    }
    // Clear the header variable
    header = "";
    // Close the connection
    client.stop();
    Serial.println("Client disconnected.");
    Serial.println("");
  }
}

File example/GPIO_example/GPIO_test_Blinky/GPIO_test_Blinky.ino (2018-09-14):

#include <SPI.h>
#include <MCP23S17.h>

MCP IOchip(0,5);  // create an object at address 0 called "IOchip" with SlaveSelect at GPIO5 pin of ESP             
                  // By default Clouduino's GPIO chip is addressed to 0.

void setup() {
  // put your setup code here, to run once:
  // Serial.begin(115200);
  IOchip.begin(); 
  
//Initialize GPIO A             //In MCP23S17
  IOchip.pinMode(1, OUTPUT);    //GPA-0 [pin 21]
  IOchip.pinMode(2, OUTPUT);    //GPA-1 [pin 22]
  IOchip.pinMode(3, OUTPUT);    //GPA-2 [pin 23]
  IOchip.pinMode(4, OUTPUT);    //GPA-3 [pin 24]
  IOchip.pinMode(5, OUTPUT);    //GPA-4 [pin 25]
  IOchip.pinMode(6, OUTPUT);    //GPA-5 [pin 26]
  IOchip.pinMode(7, OUTPUT);    //GPA-6 [pin 27]
  IOchip.pinMode(8, OUTPUT);    //GPA-7 [pin 28]
  
//Initialize GPIO B             //In MCP23S17
  IOchip.pinMode(9, OUTPUT);    //GPB-0 [pin 1]
  IOchip.pinMode(10, OUTPUT);   //GPB-1 [pin 2]
  IOchip.pinMode(11, OUTPUT);   //GPB-2 [pin 3]
  IOchip.pinMode(12, OUTPUT);   //GPB-3 [pin 4]
  IOchip.pinMode(13, OUTPUT);   //GPB-4 [pin 5]
  IOchip.pinMode(14, OUTPUT);   //GPB-5 [pin 6]
  IOchip.pinMode(15, OUTPUT);   //GPB-4 [pin 5]
  IOchip.pinMode(16, OUTPUT);   //GPB-5 [pin 6]  
}

void loop() {
  // put your main code here, to run repeatedly:
//TURN OFF GPA
 IOchip.digitalWrite(1, LOW); 
 IOchip.digitalWrite(2, LOW); 
 IOchip.digitalWrite(3, LOW); 
 IOchip.digitalWrite(4, LOW); 
 IOchip.digitalWrite(5, LOW); 
 IOchip.digitalWrite(6, LOW); 
 IOchip.digitalWrite(7, LOW); 
 IOchip.digitalWrite(8, LOW);
//TURN OFF GPB    
 IOchip.digitalWrite(9, HIGH);
 IOchip.digitalWrite(10, HIGH); 
 IOchip.digitalWrite(11, HIGH); 
 IOchip.digitalWrite(12, HIGH); 
 IOchip.digitalWrite(13, HIGH);
 IOchip.digitalWrite(14, HIGH); 
 IOchip.digitalWrite(15, HIGH);
 IOchip.digitalWrite(16, HIGH);  

 delay(1000);

//TURN ON GPA
 IOchip.digitalWrite(1, HIGH);
 IOchip.digitalWrite(2, HIGH); 
 IOchip.digitalWrite(3, HIGH); 
 IOchip.digitalWrite(4, HIGH);
 IOchip.digitalWrite(5, HIGH); 
 IOchip.digitalWrite(6, HIGH); 
 IOchip.digitalWrite(7, HIGH); 
 IOchip.digitalWrite(8, HIGH);
//TURN ON GPB
 IOchip.digitalWrite(9, LOW);
 IOchip.digitalWrite(10, LOW); 
 IOchip.digitalWrite(11, LOW); 
 IOchip.digitalWrite(12, LOW);
 IOchip.digitalWrite(13, LOW);
 IOchip.digitalWrite(14, LOW); 
 IOchip.digitalWrite(15, LOW);
 IOchip.digitalWrite(16, LOW);
 delay(1000); 
}

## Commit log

2018-08-10 Wiring updates
    -Changed wire color
2018-08-10 Revert "Wiring updates"
    This reverts commit e9a4c82155d45316598920405a4bb160099bc8ab.
2018-08-29 Clouduino
    -Rename folders and files for ease
    -Added Webserver sample code
2018-09-03 Documentation
    -minor revisions on GPIO test manual
    -Added Fritzing breadboard for Clouduino Webserver Leds example
2018-09-04 new schematic
2018-09-05 how-to
    -Added README for controlling ADC pins
    -Revised README for controlling GPIO pins
2018-09-06 Sample Sketches
    - Renamed Example Code to Sample Sketches folder
    - Added readme file about uploading sketches to Clouduino
2018-09-06 added power supply specs
2018-09-07 Mesh
    - Added PainlessMesh sample sketch
    - Added README with mesh disclaimer
2018-09-11 README
    - Revised ADC and GPIO readme
    - Added Troubleshooting section for Example Sketch readme
2018-09-14 Breadboard on Fritzing
    - Removed confusing ratsnest on breadboard
    - Rewired GPIO wires going to green LEDs for clarity
2018-09-15 Fritzing
    - Changed IC labels in breadboard-fritzing pics (MCP23S17 and MCP3208)
    - Added Clouduino_Webserver fritzing schematic and breadboard png
2018-09-15 Added Get Started guide
    - Added Quick start guide to Clouduino
    - Made a docs folder to dump .png files for Quickstart docu
    - Revised "Uploading Sketches to Clouduino using Arduino IDE" Readme (Reverted to Toggle switch for booting / Reset switch instead of replugging the board)
2018-09-15 Quick fix
    - Fixed Blink breadboard and schematic images
2018-09-18 Minor fixes and updates
    - added datasheets folder under docs
    - moved logo to images folder
    - minor revisions (spellings, grammar)
    - fixed links
    - added readme for Clouduino Webserver example for clarity
    [ADC_test_LDR.ino]
2018-09-24 Add Gerber files for fabrication
    [Clouduino Stratus v1.0-B.Cu.gbl, Clouduino Stratus v1.0-Edge.Cuts.gm1, Clouduino Stratus v1.0-F.Cu.gtl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]
2018-09-24 Clouduino on Fritzing
    +Added Clouduino fritzing file
    +Updated breadboard and schematic on fritzing
    [Clouduino_Fritzing.fzz]
2018-09-24 Fritzing for sample circuits
    + Added Fritzing files on examples
    [ADC_test_LDR.fzz, Blink_fritzing.fzz, Clouduino_Webserver_LEDs_fritzing.fzz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]
2018-09-24 Reupload
    +Reuploaded Clouduino Fritzing and pdf schematics
2018-09-26 Updated Readme
    - Added materials needed for DIY Clouduino board
2018-09-26 Minor revision
    - Removed duplicate schematics folder
    - On readme file, changed link: directory name from Schematics to schematic folder
    [Clouduino_Fritzing.fzz]
2018-09-26 Formatting
    - List of materials (from numbers to bullets)
2018-10-02 Updated gerbers
    Improved some of the silkscreen around the pins, including changing a bit of the layout around the power pins
    [Clouduino Stratus v1.0-B.Cu.gbl, Clouduino Stratus v1.0-Edge.Cuts.gm1, Clouduino Stratus v1.0-F.Cu.gtl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]
2018-10-12 Changed Schematic Version Number
    Changed schematic version number to 0.9 to reflect early stage nature of design
2019-08-18 fixed BOM
2019-08-18 Update Schematic
    Added power OR-ing section
